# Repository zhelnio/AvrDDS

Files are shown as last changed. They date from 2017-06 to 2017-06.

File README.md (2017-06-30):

# AvrDDS
ATmega88 based DDS signal generator from 2013

Old. Simple. And almost without analog part. One of my first AVR devices. It was constructed before I had passed 
[MIT 6.002](https://ocw.mit.edu/courses/electrical-engineering-and-computer-science/6-002-circuits-and-electronics-spring-2007/index.htm) 
course. Published here as an artifact of my home made electronics.

**Schematic**

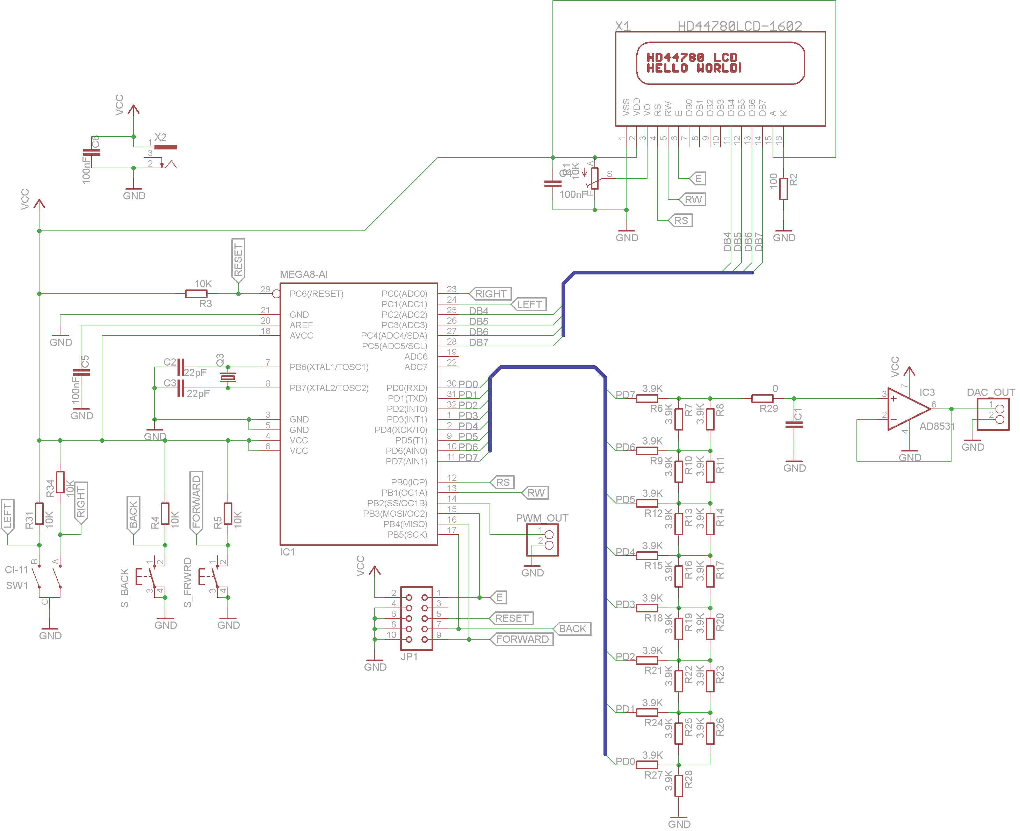
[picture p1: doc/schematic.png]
Schematic


**Board**

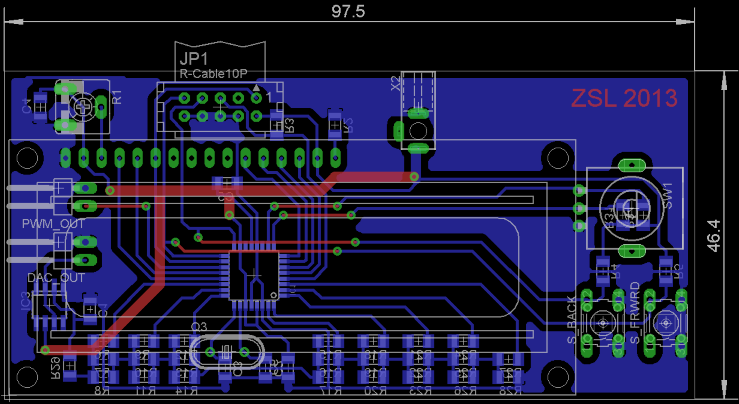
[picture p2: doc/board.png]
Board


**Menu**

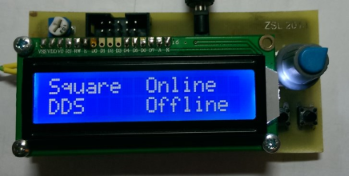
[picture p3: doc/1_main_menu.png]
Main menu

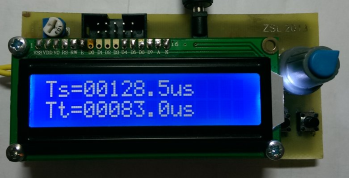
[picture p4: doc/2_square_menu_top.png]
Square signal (top)

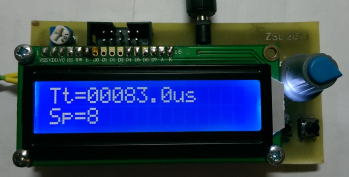
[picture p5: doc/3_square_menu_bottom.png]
Square signal (bottom)

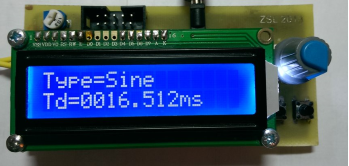
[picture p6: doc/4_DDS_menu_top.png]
DDS signal (top)

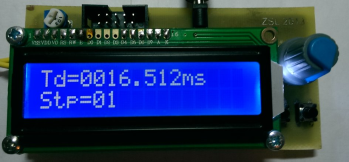
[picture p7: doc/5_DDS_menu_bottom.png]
DDS signal (bottom)


**Video of its work**

Video of work (https://www.youtube.com/watch?v=0xc064LqjQs)

Originaly published on https://bitbucket.org/zhelnio/avrdds/

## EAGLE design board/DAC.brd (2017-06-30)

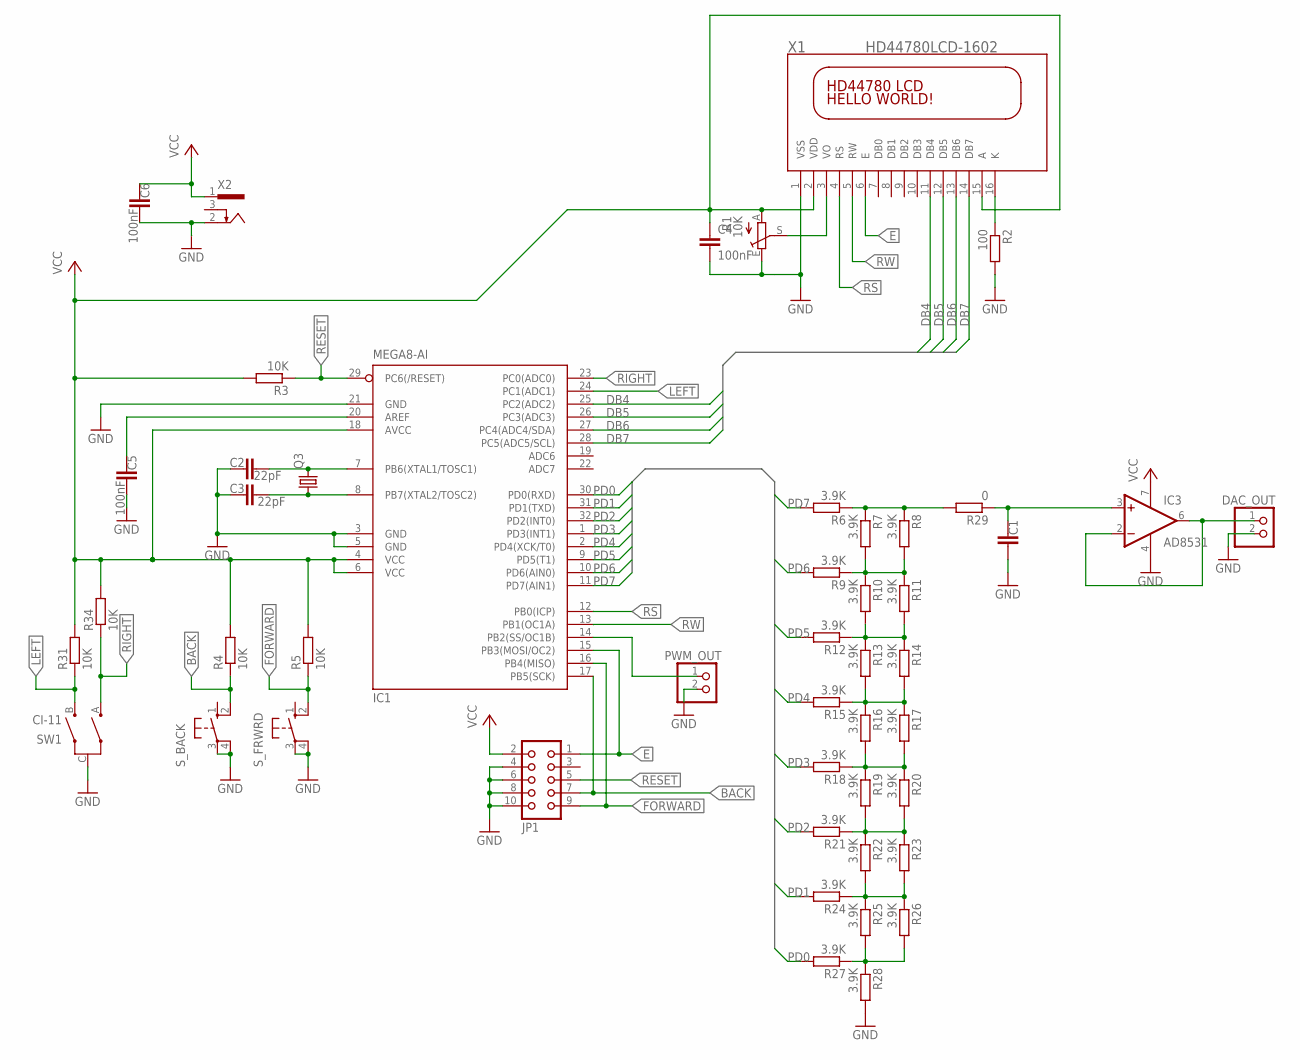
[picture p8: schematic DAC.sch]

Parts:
C1: C-EUC1206; C1206
C2, C3: 22pF; C1206
C4, C5, C6: 100nF; C1206
DAC_OUT: PINHD-1X2_2.54-90°; 1X02/90
IC1: MEGA8-AI; TQFP32-08
IC3: AD8531; SO08
JP1: CON10L
PWM_OUT: PINHD-1X2_2.54-90°; 1X02/90
Q3: CRYSTALHC49U-V; HC49U-V
R1: 10K; CA6V
R2: 100; R1206
R3, R4, R5, R31, R34: 10K; R1206
R6, R7, R8, R9, R10, R11, R12, R13, R14, R15, R16, R17, R18, R19, R20, R21, R22, R23, R24, R25, R26, R27, R28: 3.9K; R1206
R29: 0; R1206
SW1: CI-11
S_BACK: 10-XX; B3F-10XX
S_FRWRD: 10-XX; B3F-10XX
X1: HD44780LCD-1602; LCD1602
X2: 733989-5

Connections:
BACK: IC1.17 (PB5(SCK)), JP1.7, R4.1, S_BACK.2 (S1)
DB4: IC1.25 (PC2(ADC2)), X1.11 (DB4)
DB5: IC1.26 (PC3(ADC3)), X1.12 (DB5)
DB6: IC1.27 (PC4(ADC4/SDA)), X1.13 (DB6)
DB7: IC1.28 (PC5(ADC5/SCL)), X1.14 (DB7)
E: IC1.15 (PB3(MOSI/OC2)), JP1.1, X1.6 (E)
FORWARD: IC1.16 (PB4(MISO)), JP1.9, R5.1, S_FRWRD.2 (S1)
GND: C1.2, C2.1, C3.1, C4.2, C5.2, C6.2, DAC_OUT.2, IC1.3 (GND), IC1.5 (GND), IC1.21 (GND), IC3.4 (V-), JP1.4, JP1.6, JP1.8, JP1.10, PWM_OUT.2, R1.E, R2.2, R28.2, SW1.C, S_BACK.3, S_BACK.4 (P1), S_FRWRD.3, S_FRWRD.4 (P1), X1.1 (VSS), X2.2
LEFT: IC1.24 (PC1(ADC1)), R31.1, SW1.B
unnamed: DAC_OUT.1, IC3.2 (-IN), IC3.6 (OUT)
unnamed: C5.1, IC1.20 (AREF)
unnamed: C2.2, IC1.7 (PB6(XTAL1/TOSC1)), Q3.2
unnamed: R1.S, X1.3 (VO)
unnamed: R6.1, R7.1, R8.1, R29.2
unnamed: IC1.14 (PB2(SS/OC1B)), PWM_OUT.1
unnamed: R2.1, X1.16 (K)
unnamed: R7.2, R8.2, R9.1, R10.1, R11.1
unnamed: R10.2, R11.2, R12.1, R13.1, R14.1
unnamed: R13.2, R14.2, R15.1, R16.1, R17.1
unnamed: R16.2, R17.2, R18.1, R19.1, R20.1
unnamed: R19.2, R20.2, R21.1, R22.1, R23.1
unnamed: R22.2, R23.2, R24.1, R25.1, R26.1
unnamed: R25.2, R26.2, R27.1, R28.1
unnamed: C1.1, IC3.3 (+IN), R29.1
unnamed: C3.2, IC1.8 (PB7(XTAL2/TOSC2)), Q3.1
PD0: IC1.30 (PD0(RXD)), R27.2
PD1: IC1.31 (PD1(TXD)), R24.2
PD2: IC1.32 (PD2(INT0)), R21.2
PD3: IC1.1 (PD3(INT1)), R18.2
PD4: IC1.2 (PD4(XCK/T0)), R15.2
PD5: IC1.9 (PD5(T1)), R12.2
PD6: IC1.10 (PD6(AIN0)), R9.2
PD7: IC1.11 (PD7(AIN1)), R6.2
RESET: IC1.29 (PC6(/RESET)), JP1.5, R3.1
RIGHT: IC1.23 (PC0(ADC0)), R34.1, SW1.A
RS: IC1.12 (PB0(ICP)), X1.4 (RS)
RW: IC1.13 (PB1(OC1A)), X1.5 (RW)
VCC: C4.1, C6.1, IC1.4 (VCC), IC1.6 (VCC), IC1.18 (AVCC), IC3.7 (V+), JP1.2, R1.A, R3.2, R4.2, R5.2, R31.2, R34.2, X1.2 (VDD), X1.15 (A), X2.1

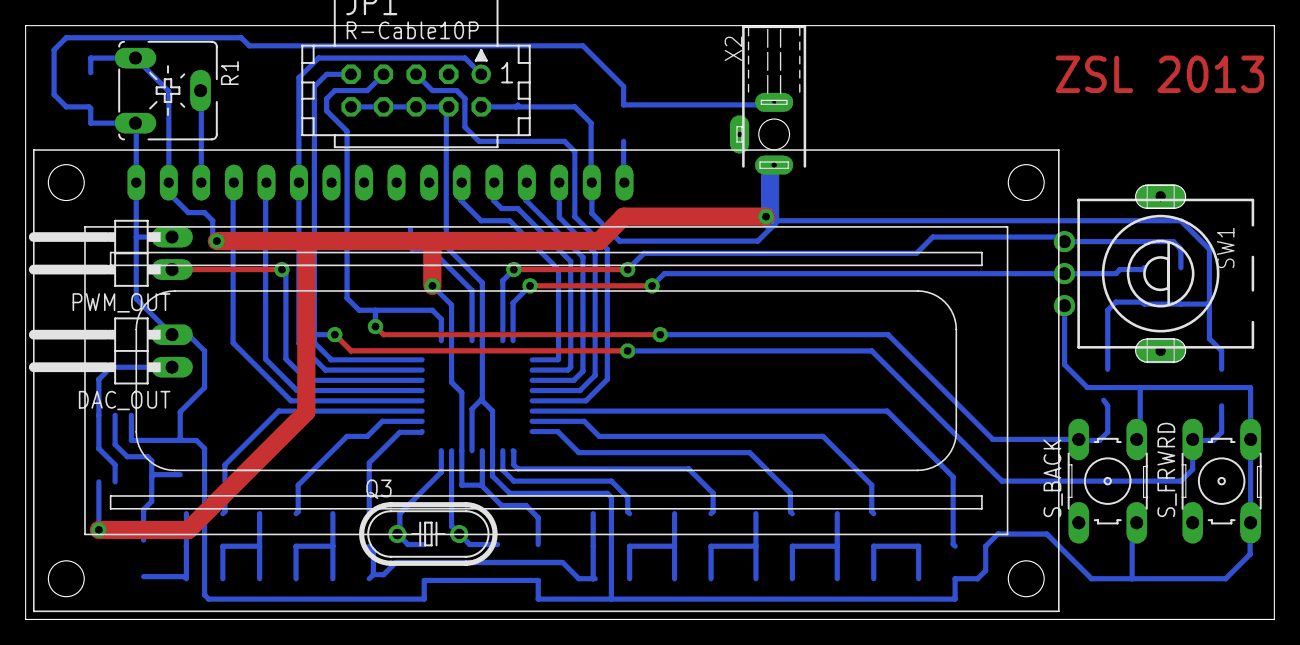
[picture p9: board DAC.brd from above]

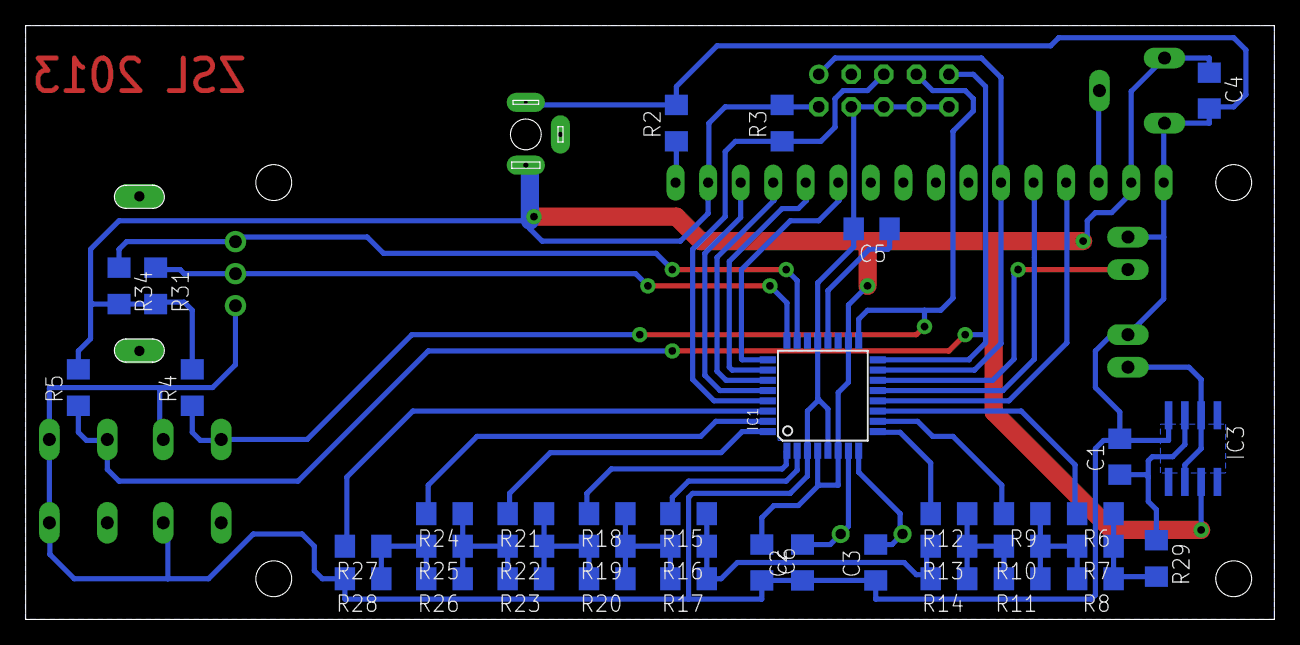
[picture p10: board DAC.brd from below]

Board: 2 copper layers, 97.5 x 46.3 mm, 48 parts (38 on the bottom side), 38 nets.

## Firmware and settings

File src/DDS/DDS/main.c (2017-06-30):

/* Автор:              Stanislav Zhelnio (https://twitter.com/zhelnio)
 * Тип МК:			   ATmega88, Flash 8 Kbytes, SRAM 1 Kbytes, EEPROM 512 bytes.
 * Тактовая частота:   F_CPU 16000000 MHz
 * Дата:               07.01.2014
 * Версия ПО:          Atmel Studio 6 (Version: 6.1.2730 - Service Pack 2)
 * FUSES:              HIGH 0xdf, LOW 0xff;
 * Описание:           Software for ATmega88-based DDS with LCD1602, PWM-out on PB2 (OC1B), DDS-out to ADC on PORTD 
 
					   Thanks to:
					   DI HALT for PINBOARD-II developement board and http://easyelectronics.ru/ web resource
					   Papandopala Papandopalavich for his LCD library
					   (http://we.easyelectronics.ru/AVR/biblioteka-na-si-dlya-lcd-displeev-na-baze-processora-hd44780-dlya-mikrokontrollerov-avr.html)
					   Steel.ne for idia of menu structure 
					   (http://easyelectronics.ru/organizaciya-drevovidnogo-menyu.html)
 */

#include "common.h"

//menu

//основной массив элементов меню
//определяет:
// - идентификаторы пунктов меню (должны идти в порядке их объявления в enum eItem !)
// - связи между элементами (следующий/предыдущий/дочерний/родительский),
// - функции обработчики событий (кнопки/вход-выход)
// - наименование пункта меню/параметра
// - функции преобразователи в строку
// всю основную работу с этим массивом выполняет процедура doAction

MenuItem globalMenuData[] = {
	// порядок перечисления должен соответствовать таковому в enum eItem (!)
	//	ID,			NXT,		PRV,		PRN,		CHLD,		ButtonAction,	ModeAction,	CAPTION		ToString
	{	mSquare,	mDds,		mNothing,	mNothing,	mSquareTs,	NULL,	doSquareModeAction,	"Square",	SquareItemToString },
	{	mDds,		mNothing,	mSquare,	mNothing,	mDdsSignal,	NULL,	doDdsModeAction,	"DDS",		DdsItemToString },
		
	{	mSquareTs,	mSquareTt,	mNothing,	mSquare,	mNothing,	doSquareButtonAction,	doSquareModeAction,	"Ts",	SquareItemToString },
	{	mSquareTt,	mSquareSp,	mSquareTs,	mSquare,	mNothing,	doSquareButtonAction,	doSquareModeAction,	"Tt",	SquareItemToString },
	{	mSquareSp,	mNothing,	mSquareTt,	mSquare,	mNothing,	doSquareButtonAction,	doSquareModeAction,	"Sp",	SquareItemToString },
	
	{	mDdsSignal,	mDdsDelay,	mNothing,	mDds,		mNothing,	doDdsButtonAction,		doDdsModeAction,	"Type",	DdsItemToString },
	{	mDdsDelay,	mDdsStep,	mDdsSignal,	mDds,		mNothing,	doDdsButtonAction,		doDdsModeAction,	"Td",	DdsItemToString },
	{	mDdsStep,	mNothing,	mDdsDelay,	mDds,		mNothing,	doDdsButtonAction,		doDdsModeAction,	"Stp",	DdsItemToString }
};

int main(void)
{
	LCDinit();
	
	DDRD = 0xFF;
	DDRB |= (1<<PINB2);
	
	//разрешаем прерывания по смене напряжения на входе
	PCICR |= (1 << PCIE0) | (1 << PCIE1);
	PCMSK0 |= (1 << PCINT4) | (1 << PCINT5);
	PCMSK1 |= (1 << PCINT8) | (1 << PCINT9);
	
	//загрузка настроек
	loadDdsSettings();
	loadSquareSettings();
	
	//установка и вывод меню
	initMenu(&globalMenuData[mSquare]);
	
	sei();	
	
    while(1)
	{
		//непосредственно выполняет генерациюю на порт DDS
		checkStopFlagAndDoDdsSignalOut();
	}
}

//прерывания от кнопок назад/вперед
ISR(PCINT0_vect)
{
	//состояние портов на момент последнего изменения
	static volatile uint8_t portbhistory = 0xFF;
	
	//определяем изменившиеся биты
	uint8_t changedbits = PINB ^ portbhistory;
	portbhistory = PINB;
	
	if( (changedbits & (1 << PINB4)) && (portbhistory & (1 << PINB4)) )
		doAction(buttonRight);
	
	if( (changedbits & (1 << PINB5)) && (portbhistory & (1 << PINB5)) )
		doAction(buttonLeft);
	
	_delay_ms(100);
}

//прерывания от энкодера лево/право
ISR(PCINT1_vect)
{
	static uint8_t EncState = 0x00;
	uint8_t newValue = PINC & 0x03;
	uint8_t fullState = EncState | newValue << 2;
	
	switch(fullState)
	{
		case 0xB: case 0xD: // case 0x2: case 0x4:
		doAction(buttonUp);
		break;
		case 0x7: case 0xE: // case 0x1:  case 0x8:
		doAction(buttonDown);
		break;
	}
	EncState = newValue;
}

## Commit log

2017-06-30 firmware source
    [generationMode.xlsx]
2017-06-30 hardware schematic
    [DAC.brd, DAC.sch]
